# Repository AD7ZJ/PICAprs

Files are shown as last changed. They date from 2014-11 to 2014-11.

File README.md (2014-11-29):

# PIC based APRS Tracking Beacon

I started this project as a fun experiment to see if I could generate an AFSK signal with a small PIC and a resistor ladder network.  It worked out well so I made it into a full tracking beacon.  We fly these on high altitude balloons to track and recover the balloon's payload.  Here's a few of the key features:

- Simple and inexpensive to build.  AFSK is generated using a resistor network so no modem chip is needed
- Adjustable audio output allows interfacing with a variety of radios
- Integrated GPS with helical antenna - no cables to break and works in any orientation
- NMEA data from the GPS is stored on a FAT32 formatted micro SD card
- Software is modular and easy to understand

Well, the last one might be open to debate :-)  It runs on a PIC18F2525 with an SD card hooked up to the SPI port.  I put the GPS and GPS antenna on the same PCB but unfortunately that antenna can no longer be bought from sparkfun - Sarantel seems to be out of business. 

An MPLAB-X project is included and works with the latest version (2.26).  I use the Microchip XC8 compiler.  More details can be seen here: http://wiki.ad7zj.net/wiki/index.php/PIC_APRS_Beacon

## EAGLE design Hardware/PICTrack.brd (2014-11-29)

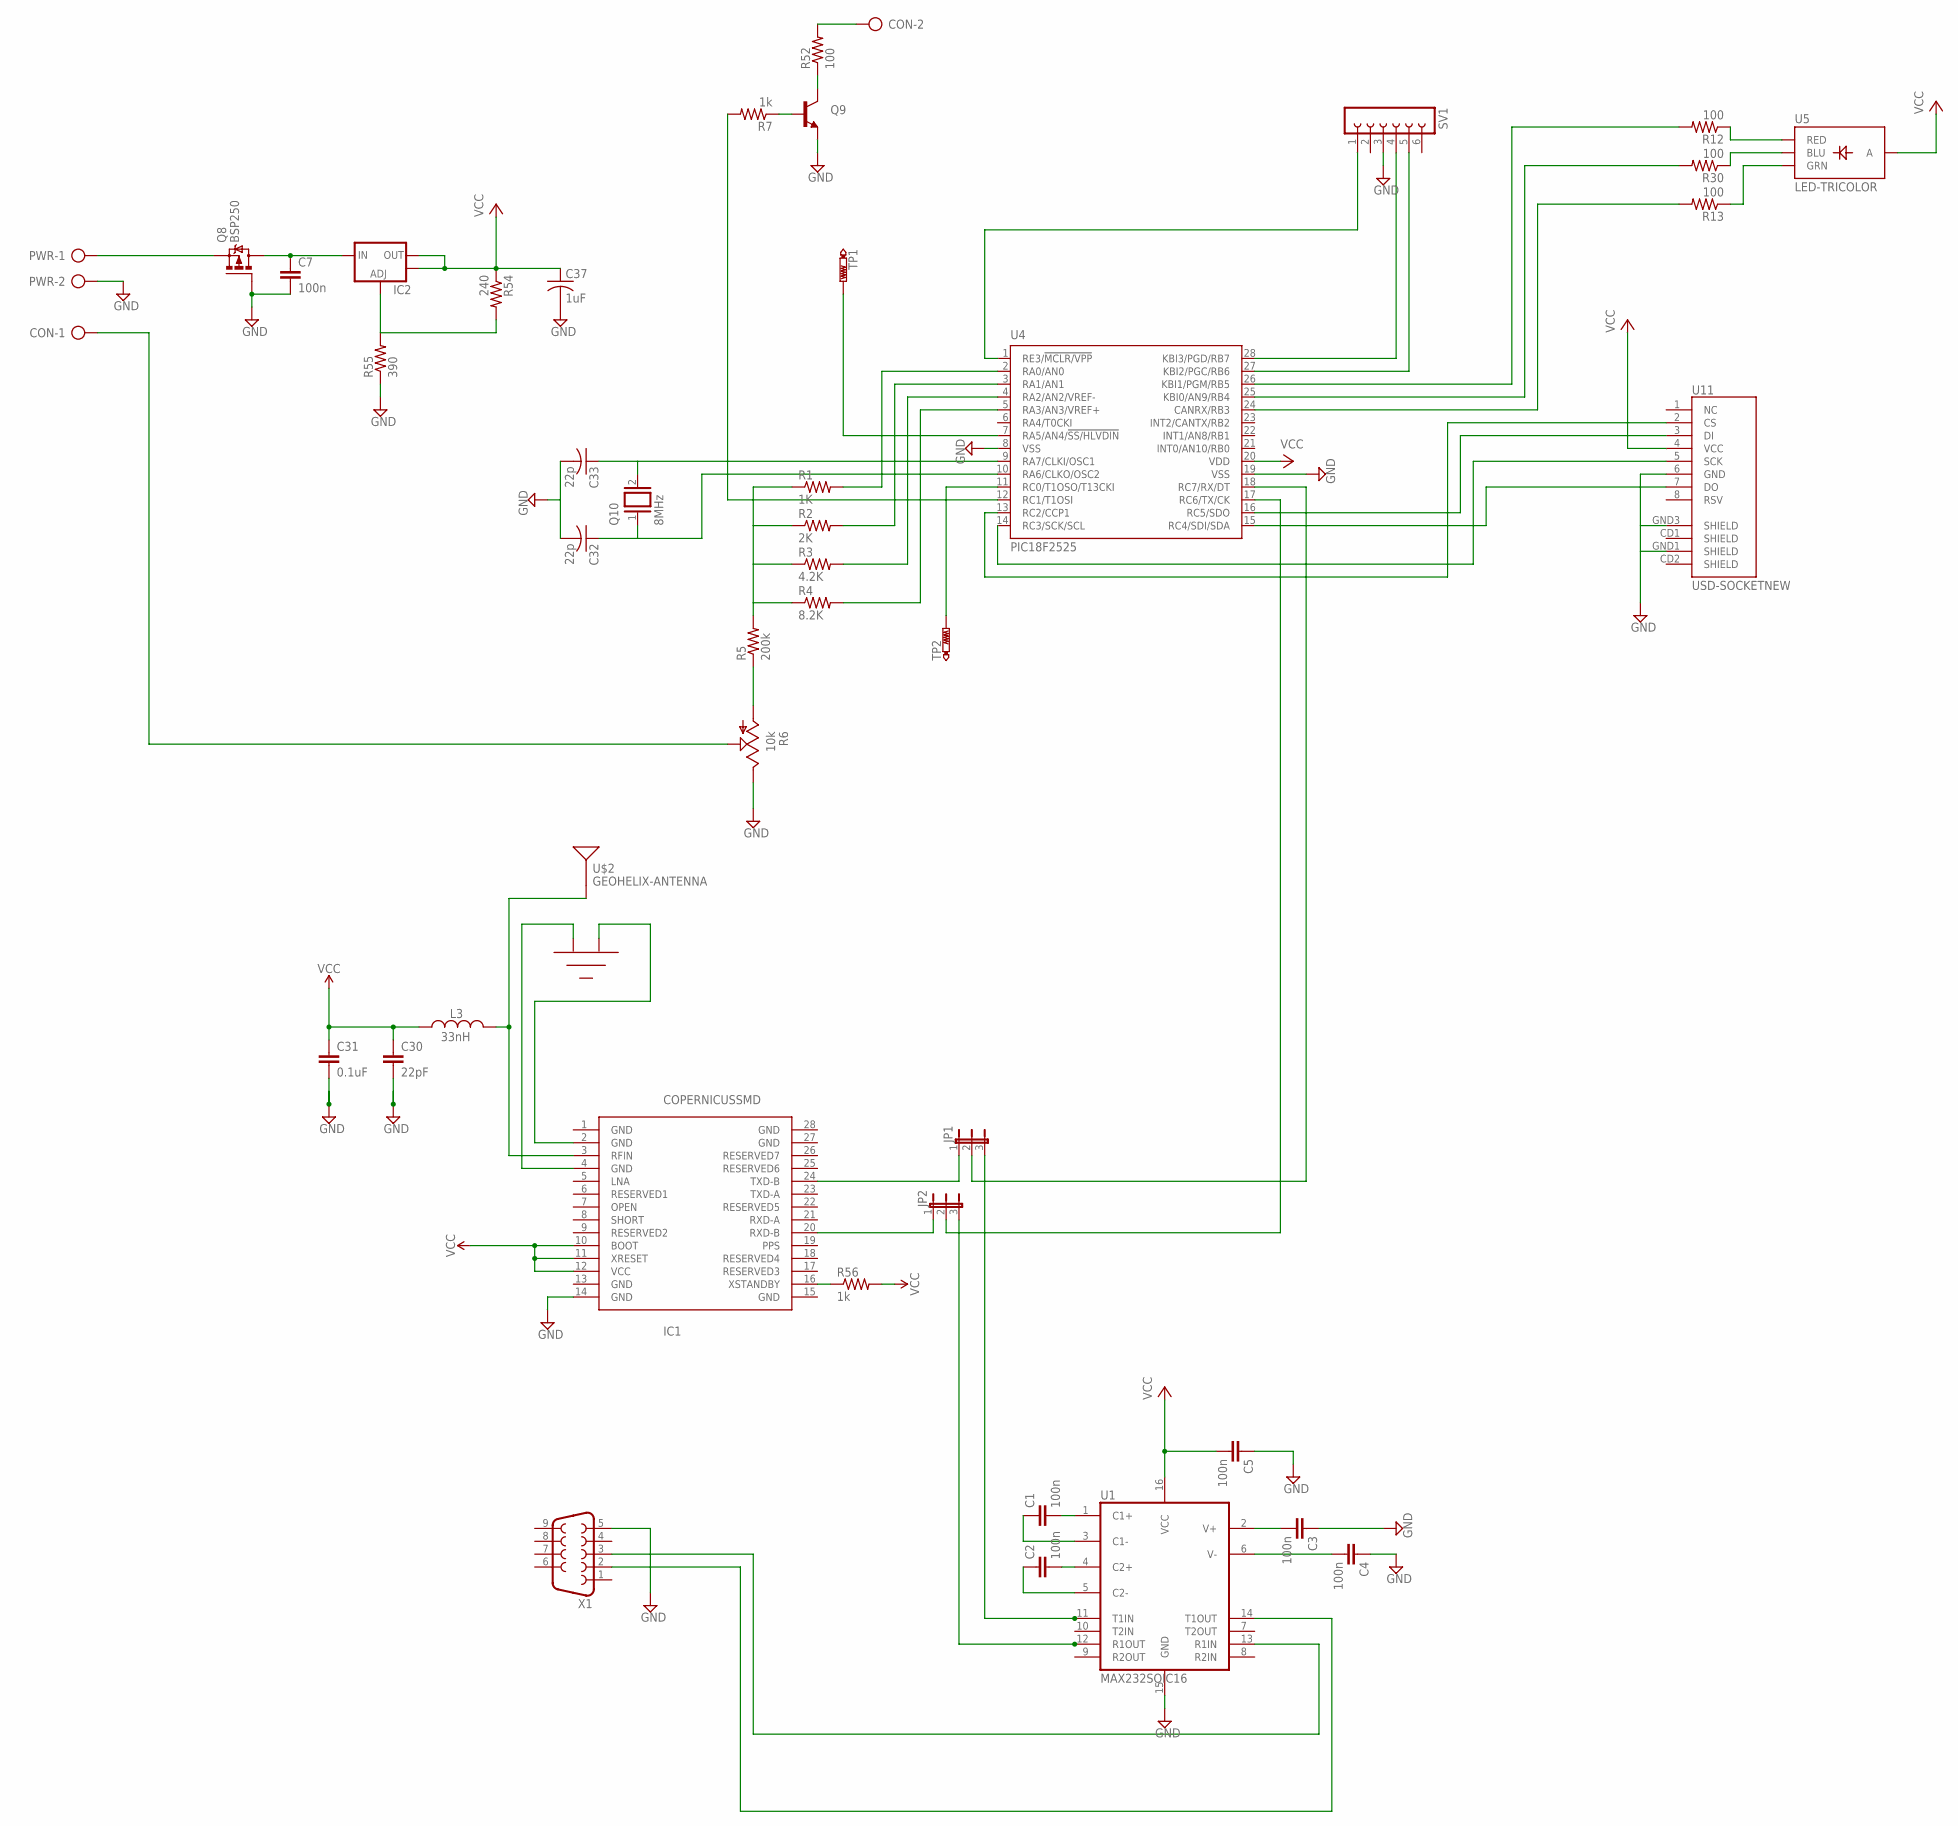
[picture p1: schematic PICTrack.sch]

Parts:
C1, C2, C3, C4, C5, C7: 100n; C0402
C30: 22pF; 0402-CAP
C31: 0.1uF; 0402-CAP
C32, C33: 22p; C0603
C37: 1uF; C025-030X050
CON: AK300/2
IC1: COPERNICUSSMD; COPERNICUS
IC2: V_REG_LM1117SOT223; SOT223
JP1, JP2: JP2E; JP2
L3: 33nH; C0402
PWR: AK300/2
Q8: BSP250; SOT223
Q9: TRANSISTOR_NPNSOT23; SOT23
Q10: 8MHz; QS
R1: 1K; 0411V
R2: 2K; 0411V
R3: 4.2K; 0411V
R4: 8.2K; 0411V
R5: 200k; 0411V
R6: 10k; CA6V
R7, R56: 1k; R0603
R12, R13, R30: 100; R0603
R52: 100; 0411V
R54: 240; R0603
R55: 390; R0603
SV1: FE06-1; FE06
TP1, TP2: PTR1PAD1-13; P1-13
U1: MAX232SOIC16; SO016
U4: PIC18F2525; SO28W
U5: LED-TRICOLOR; LED-TRICOLOR-SMD
U11: USD-SOCKETNEW; MICRO-SD-SOCKET-PP
U$2: GEOHELIX-ANTENNA; HELIXANTENNA
X1: DB9FEMALE; DB9

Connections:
GND: C3.1, C4.1, C5.1, C7.2, C30.2, C31.2, C32.2, C33.2, C37.2, IC1.14 (GND), PWR.2, Q8.1 (G), Q9.2 (E), R6.E, R55.1, SV1.3, U1.15 (GND), U4.8 (VSS), U4.19 (VSS), U11.6 (GND), U11.GND1 (SHIELD), U11.GND3 (SHIELD), X1.5
unnamed: R5.1, R6.A
unnamed: R1.2, U4.2 (RA0/AN0)
unnamed: R2.2, U4.3 (RA1/AN1)
unnamed: R3.2, U4.4 (RA2/AN2/VREF-)
unnamed: R4.2, U4.5 (RA3/AN3/VREF+)
unnamed: R1.1, R2.1, R3.1, R4.1, R5.2
unnamed: PWR.1, Q8.3 (S)
unnamed: C1.2, U1.1 (C1+)
unnamed: CON.1, R6.S
unnamed: C1.1, U1.3 (C1-)
unnamed: C2.2, U1.4 (C2+)
unnamed: C2.1, U1.5 (C2-)
unnamed: C3.2, U1.2 (V+)
unnamed: C4.2, U1.6 (V-)
unnamed: SV1.1, U4.1 (RE3/!MCLR/VPP)
unnamed: SV1.4, U4.28 (KBI3/PGD/RB7)
unnamed: IC1.2 (GND), U$2.P$3 (GND1)
unnamed: TP1.TP, U4.7 (RA5/AN4/!SS/HLVDIN)
unnamed: IC1.16 (XSTANDBY), R56.1
unnamed: R12.1, U5.R (RED)
unnamed: R30.1, U5.B (BLU)
unnamed: TP2.TP, U4.11 (RC0/T1OSO/T13CKI)
unnamed: JP1.3, U1.11 (T1IN)
unnamed: IC2.1 (ADJ), R54.2, R55.2
unnamed: Q9.3 (C), R52.1
unnamed: CON.2, R52.2
unnamed: R7.2, U4.12 (RC1/T1OSI)
unnamed: Q9.1 (B), R7.1
unnamed: IC1.4 (GND), U$2.P$1 (GND)
unnamed: U1.13 (R1IN), X1.3
unnamed: U1.14 (T1OUT), X1.2
unnamed: SV1.5, U4.27 (KBI2/PGC/RB6)
unnamed: U4.15 (RC4/SDI/SDA), U11.7 (DO)
unnamed: U4.14 (RC3/SCK/SCL), U11.5 (SCK)
unnamed: U4.16 (RC5/SDO), U11.3 (DI)
unnamed: U4.13 (RC2/CCP1), U11.2 (CS)
unnamed: IC1.24 (TXD-B), JP1.1
unnamed: C32.1, Q10.1, U4.10 (RA6/CLKO/OSC2)
unnamed: C33.1, Q10.2, U4.9 (RA7/CLKI/OSC1)
unnamed: JP2.3, U1.12 (R1OUT)
unnamed: IC1.20 (RXD-B), JP2.1
unnamed: C7.1, IC2.3 (IN), Q8.2 (D)
unnamed: R13.1, U5.G (GRN)
unnamed: R12.2, U4.26 (KBI1/PGM/RB5)
unnamed: R30.2, U4.25 (KBI0/AN9/RB4)
unnamed: R13.2, U4.24 (CANRX/RB3)
RFIN: IC1.3 (RFIN), L3.2, U$2.P$2 (SIGNAL)
RXD: JP2.2, U4.17 (RC6/TX/CK)
TXD: JP1.2, U4.18 (RC7/RX/DT)
VCC: C5.2, C30.1, C31.1, C37.1, IC1.10 (BOOT), IC1.11 (XRESET), IC1.12 (VCC), IC2.2 (OUT), IC2.4 (OUT), L3.1, R54.1, R56.2, U1.16 (VCC), U4.20 (VDD), U5.A, U11.4 (VCC)

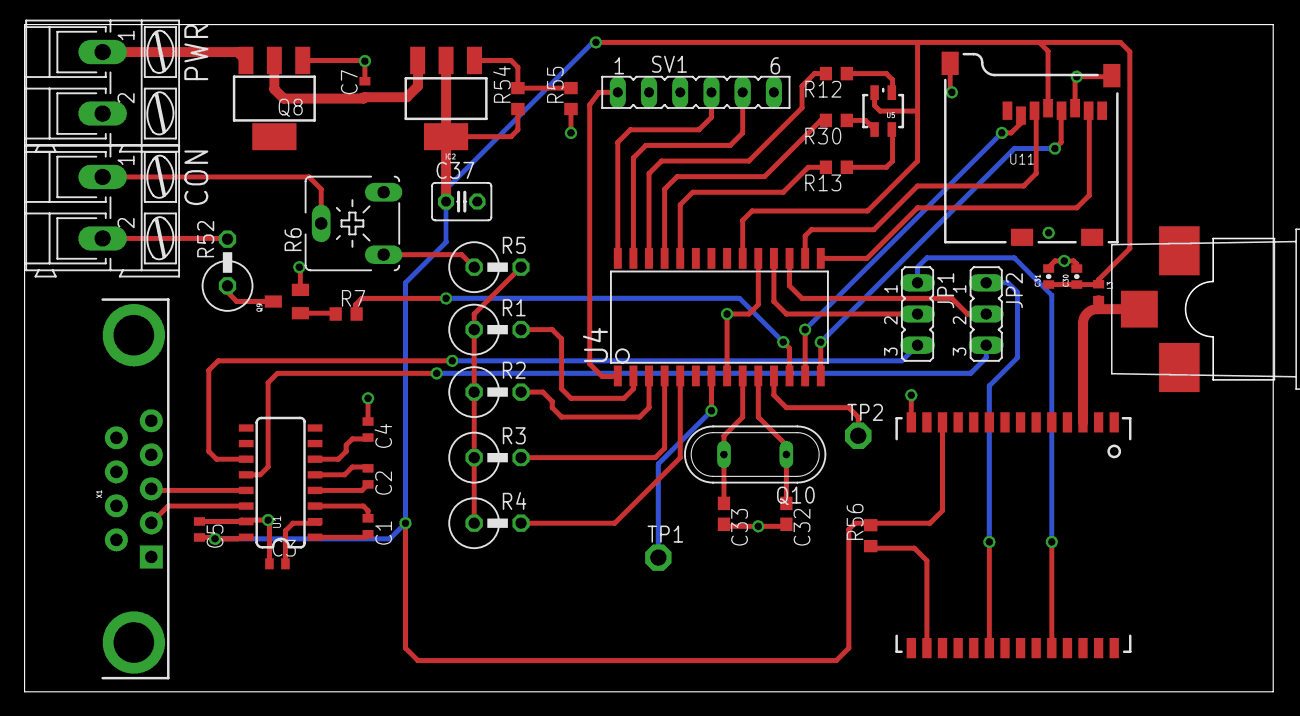
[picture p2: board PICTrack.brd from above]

Board: 2 copper layers, 101.6 x 54.3 mm, 44 parts (0 on the bottom side), 51 nets.

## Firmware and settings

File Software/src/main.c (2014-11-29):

/**
 * @mainpage PICAprs
 *
 * @section overview_sec Overview
 *
 * PICAprs aims to be a self-contained APRS based tracking system that generates
 * modulated audio (AFSK) to interface with an FM transmitter.  It uses an on-board
 * 4 bit resistor DAC followed by an RC LPF to generate the audio.  It expects NMEA
 * (GGA and RMC strings) in from a GPS on the hardware UART ports.  Currently
 * it's designed to run on a Microchip PIC18F2525 clocked at 32 Mhz although porting
 * to another architecture shouldn't be too difficult.  Timing during the packet
 * generation routine is pretty tight and requires interrupts to be disabled until
 * the packet is finished sending.  
 *
 * @section copyright_sec Copyright
 *
 * Copyright (c) 2013 Elijah Brown, AD7ZJ
 *
 *
 * @section gpl_sec GNU General Public License
 *
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
 *
 * @section history_sec Revision History
 *
 *         @subsection v001 V0.01
 *         03 Nov 2013, Initial release.
 *         @subsection v100 V1.00
 *         01 Mar 2014, Release for first flight
 *         @subsection v101 V1.01
 *         25 Jul 2014, Sin lookup table error fixed and experimentally
 *                      tuned the symbol clocks to be closer to nominal values.
 *
 * @defgroup app Main Application
 *
 * @{
 */

#include <htc.h>
#include <stdio.h>
#include <stdlib.h>
#include <string.h>
#include "main.h"
#include "tnc.h"
#include "serial.h"
#include "Engineering.h"
#include "led.h"
#include "fifo.h"
#include "gps.h"
#include "mic-e.h"
#include <math.h>
#include "ff.h"
#include "sd.h"

/// Needed by the compiler for _delay() routines
#define _XTAL_FREQ  32000000

/// Number of system timer ticks in one second
#define ONE_SEC     20
#define FIVE_SEC    100

/*
 * Fuse settings
 */
#pragma config OSC      = INTIO67
#pragma config WDT      = OFF
#pragma config BOREN    = OFF
#pragma config DEBUG    = ON
#pragma config MCLRE    = OFF
#pragma config LVP      = OFF

/*
 * Forward definitions
 */
void sysInit(void);
void LedBootBlink(void);

/// Enumeration of serial port modes
typedef enum {
    STARTUP,
    GPS_MODE,
    CONSOLE_MODE
} SER_PORT_MODE;

/// Holds the last received byte from the serial port
volatile char serbuff = 0;

/// system 50ms timer tick
volatile static uint32_t sysTick;

/// keeps track of the one second tick
static uint32_t oneSecTick;

/// keeps track of the GPS status LED's tick
static uint32_t statusLedOffTick;

/// Keeps track of whether the serial port is in console mode or GPS mode
SER_PORT_MODE serMode;

/**
 * Sends a MIC-E position packet
 *
 * @param gps GPSData structure containing location to send
 */
void SendPosition(GPSData * gps) {
    MicEEncode(gps);
    TncPreparePacket(MicEGetInfoField(), MicEGetDestAddress());
    printf("Lat: %ld Long: %ld\r\n", gps->latitude, gps->longitude);

    // transmit the Mic-E compressed packet
    RadioTX();
    TncSendPacket();
    RadioRX();
}

/**
 * Sends an AX.25 status packet
 *
 * @param gps GPSData structure from which to get altitude, dop, and number of tracked satelites
 */
void SendStatus(GPSData * gps) {
    char buffer[50];
    sprintf(buffer, ">ANSR %ld' %d.%01ddop %dtrk www.ansr.org\015", (int32_t)(gps->altitude / 30.48), (uint16_t)(gps->dop / 10), (uint16_t)(gps->dop % 10), (uint16_t)gps->trackedSats);
    TncPreparePacket(buffer, "APRS  ");
    printf("%s\n", buffer);

    // transmit the packet
    RadioTX();
    TncSendPacket();
    RadioRX();
}

FATFS fileSystem;   /* Work area (file system object) for logical drive */
FIL logFile;

/**
 * Main application loop
 */
void main(void) {
    FRESULT res;
    WORD bw, btw;
    char buffer[80];

    sysInit();
    SerialInit();
    GPSData * gps;

    // get the pointer to the GPS data structure
    gps = GpsGetData();

    // configure the TNC
    TncConfigDefault();

    // indicate the system is up and running
    LedBootBlink();

    SetLED(3, 1);
    // wait for someone to press '`' a few times to enter console mode
    SerialPutst("Press '`' to enter console mode\r\n");
    while (sysTick < FIVE_SEC) {
        if (serbuff == '`') {
            serMode = CONSOLE_MODE;
            break;
        }
    }
    SetLED(3, 0);


    /* Register work area to the default drive */
    res = f_mount(&fileSystem, "", 0);
    if (res)
        printf("Failed to mount filesystem!\r\n");

    /* Open a text file */
    res = f_open(&logFile, "test.txt", FA_OPEN_ALWAYS | FA_WRITE);
    if (res)
        printf("Failed to open file: %d\r\n", res);

    /* seek to end of the file */
    f_lseek(&logFile, f_size(&logFile));

    // if console mode was not selected, default to using the GPS
    if (serMode != CONSOLE_MODE) {
        serMode = GPS_MODE;
        
        TncPreparePacket(">Successful boot!\015", "APRS  ");
        // transmit the packet
        RadioTX();
        TncSendPacket();
        RadioRX();
    }

    while (1) {
        if (serMode == CONSOLE_MODE)
            EngineeringConsole();
        else {
            // Read data from the GPS
            GpsUpdate();

            if (GpsIsDataReady()) {
                if (gps->fixType != NoFix) {
                    switch (gps->seconds) {
                        case 15:
                        case 45:
                            SendPosition(gps);
                            break;

                        case 23:
                            // send a status packet
                            SendStatus(gps);
                            break;
                    }
                }
                SetLED(1, 1);
                if (gps->fixType == NoFix)
                    statusLedOffTick = sysTick + 10;
                else
                    statusLedOffTick = sysTick + 2;
            }

            // 5s tasks
            if (sysTick > oneSecTick) {
                //printf("Uptime: %ul\r\n", uptime);
                oneSecTick = sysTick + FIVE_SEC;

                SetLED(3, 1);

                f_sync(&logFile);

                SetLED(3, 0);
            }

            // update the GPS status LED
            if (sysTick > statusLedOffTick)
                SetLED(1, 0);
        }
    }
}

/**
 * Blink the LEDs in a pattern to signal a successful boot
 */
void LedBootBlink(void) {
    uint8_t i;
    for (i = 0; i < 3; i++) {
        SetLED(1, 1);
        __delay_ms(10);
        SetLED(1, 0);
        SetLED(2, 1);
        __delay_ms(10);
        SetLED(2, 0);
        SetLED(3, 1);
        __delay_ms(10);
        SetLED(3, 0);
        __delay_ms(10);
        __delay_ms(10);
        __delay_ms(10);
    }
}

/**
 * Initialize hardware
 */
void sysInit(void) {
    // port directions: 1=input, 0=output
    LATA = 0x00;
    TRISA = 0b00000000;
    LATB = 0x00;
    TRISB = 0b00000000;
    LATC = 0x00;
    TRISC = 0b11010000;

    // multiply internal 8 MHz clock x4
    OSCCON = 0b01110000;
    PLLEN = 0x01;
    // All digital inputs
    ADCON1 = 0x0F;

    // Clear the timers
    TMR1H = 0x00;
    TMR1L = 0x00;

    // Enable timer 1
    T1CONbits.TMR1ON = 0x1;
    // System clock is not derived from Timer1 Osc
    T1CONbits.T1RUN = 0x0;
    // Timer1 Osc is disabled
    T1CONbits.T1OSCEN = 0x0;
    // Use Fosc/4 for the clock source
    T1CONbits.TMR1CS = 0x0;
    // prescaler of 1:8
    T1CONbits.T1CKPS = 0x3;
    // enable its interrupt
    TMR1IE = 0x01;

    // enable Timer2
    T2CONbits.TMR2ON = 0x1;
    // Prescale of 1:2
    T2CONbits.T2OUTPS0 = 0x1;

    // GIE, PEIE Interrupts
    GIE = 0x1;
    PEIE = 0x1;
    INTCON = 0b11000000;
    RCIE = 0x01;

    // Put the serial port in startup mode
    serMode = STARTUP;

    // zero the uptime
    sysTick = 0;

    sysTick = 0;
    oneSecTick = 0;
    statusLedOffTick = 0;
}

/**
 * System interrupt handler
 */
interrupt isr(void) {
    // Serial receive interrupt
    if (RCIF) {
        serbuff = RCREG;
        if (serMode != STARTUP) {
            FifoWrite(serbuff);
        }

        // clear any overrun errors
        if (OERR)
        {
            CREN=0;
            CREN=1;
        }
    }

    // Timer 1 interrupt every 50ms
    if (TMR1IF) {
        // Clear interrupt flag & reload timer
        TMR1IF = 0x00;
        TMR1H = 0x3C;
        TMR1L = 0xAF;
        sysTick++;

        // update the filesystem timers
        disk_timerproc();
    }
}

/** @} */

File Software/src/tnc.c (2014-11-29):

#include <htc.h>
#include <string.h>
#include "main.h"
#include "tnc.h"
#include "fifo.h"
#include "serial.h"

/**
 * @defgroup ax25packet AX.25 Packet Creation
 *
 * Contains functions to control the 4-bit resistor DAC, create packets, 
 * and setup the software TNC
 * @{
 */

/**
 * Table of values to generate a sin wave.  Each value represents the value
 * to jump to after an equal increment in time.  Note this is highly dependant
 * on the particular HW configuration :-)
 */
static unsigned char sinDAC[] = {
    0b0001, 0b0101, 0b1011, 0b0111, 0b1111, 0b0111,
    0b1011, 0b0101, 0b0001, 0b1010, 0b0100,
    0b1000, 0b0000, 0b1000, 0b0100, 0b1010
};

static uint16_t tncIndex, tncLength;
static uint8_t tncBitCount, tncShift, tncLastBit, tncMode;
static uint8_t tncBitStuff, tncBuffer[TNC_MAX_TX], sinIndex;
static uint16_t timeElapsed = 0;

/// Structure containing the TNC configuration (callsign, digi path, etc)
CONFIG_STRUCT config;

#define _XTAL_FREQ 32000000

/**
 * Configure the TNC's callsign, SSID, and digipeat path.
 */
void TncConfigDefault() {
    // Station ID, relay path, and destination call sign and SSID.
    strcpy(config.callSign, "AD7ZJ ");
    config.callSignSSID = 11;
    strcpy(config.destCallSign, "APRS  ");
    strcpy(config.relayCallSign1, "GATE  ");
    strcpy(config.relayCallSign2, "WIDE2 ");
    config.relayCallSignSSID1 = 0;
    config.relayCallSignSSID2 = 1;

    // Number of TNC flag bytes sent before data stream starts.  (350mS) 1 byte = 6.6mS
    config.txDelay = 53;

    // Flight operation time.
    config.flightTime = 0;
}

/**
 * Calculate the CRC-16 CCITT of <b>buffer</b> that is <b>length</b> bytes long.
 *
 * @param buffer Pointer to data buffer.
 * @param length number of bytes in data buffer
 *
 * @return CRC-16 of buffer[0 .. length]
 */
uint16_t CRC16(uint8_t *buffer, uint16_t length) {
    uint16_t i, dbit, crc, value;

    crc = 0xffff;

    for (i = 0; i < length; ++i) {
        value = buffer[i];

        for (dbit = 0; dbit < 8; ++dbit) {
            crc ^= (value & 0x01);
            crc = (crc & 0x01) ? (crc >> 1) ^ 0x8408 : (crc >> 1);
            value = value >> 1;
        }
    }

    return crc ^ 0xffff;
}

/**
 * Prepare an AX.25 packet for transmission.  This function takes a char buffer as
 * input and operates on tncBuffer.
 *
 * @param message pointer to NULL terminate message string
 * @param destaddr pointer to the destination address
 */
void TncPreparePacket(uint8_t * message, uint8_t * destaddr) {
    uint16_t i, crc;
    uint8_t *outBuffer;

    // If we are currently sending, then ignore this packet.
    if (tncMode == TNC_TX_PREPARE || tncMode == TNC_TX_SYNC || tncMode == TNC_TX_DATA || tncMode == TNC_TX_END)
        return;

    tncMode = TNC_TX_PREPARE;

    // Set a pointer to our output buffer.
    outBuffer = tncBuffer;

    // Includes source (7), dest (7), control field (1), protocol ID (1), and end of message (1).
    tncLength = 17;

    // Set the destination address.  AX.25 requires all callsigns to be ASCI shifted one left.  This
    // essentially just drops the parity bit
    for (i = 0; i < 6; ++i)
        *outBuffer++ = destaddr[i] << 1;

    // Set destination to SSID-0
    *outBuffer++ = 0x60;

    // Set the source address, again shifted one left
    for (i = 0; i < 6; ++i)
        *outBuffer++ = config.callSign[i] << 1;

    // Set the SSID.
    *outBuffer++ = 0x60 | (config.callSignSSID << 1);

    // Add relay path 1.
    if (*config.relayCallSign1 != 0) {
        for (i = 0; i < 6; ++i)
            *outBuffer++ = config.relayCallSign1[i] << 1;
        *outBuffer++ = 0x60 | (config.relayCallSignSSID1 << 1);
        tncLength += 7;
    }

    // Add relay path 2.
    if (*config.relayCallSign2 != 0) {
        for (i = 0; i < 6; ++i)
            *outBuffer++ = config.relayCallSign2[i] << 1;
        *outBuffer++ = 0x60 | (config.relayCallSignSSID2 << 1);
        tncLength += 7;
    }

    // Set bit-0 of the last SSID.
    *(outBuffer - 1) |= 0x01;

    // Set the control field (UI) and protocol ID.
    *outBuffer++ = 0x03;
    *outBuffer++ = 0xf0;

    // Add the message to the buffer
    while (*message != 0) {
        *outBuffer++ = *message++;
        ++tncLength;
    }

    // Add the end of message character.
    *outBuffer++ = 0x0d;

    // Calculate and append the CRC.
    crc = CRC16(tncBuffer, tncLength);
    *outBuffer++ = crc & 0xff;
    *outBuffer = (crc >> 8) & 0xff;

    // Update the length to include the 2 CRC bytes.
    tncLength += 2;

    // Prepare to send the packet
    tncBitCount = 0;
    tncShift = 0x7e;
    tncLastBit = 0;
    tncIndex = 0;
    tncMode = TNC_TX_SYNC;
}

/**
 * Generate a continuous mark or space tone to allow for frequency calibration
 *
 * @param bitValue zero for a 1200hz tone, non-zero for a 2200hz tone
 */
void TncCalTones(unsigned bitValue) {
    while (FifoRead() != 'q') {
        // Output the next step of the sin wave.  The rest of the code in this function determines the
        // frequency of this wave.
        PORTC = sinDAC[sinIndex];
        sinIndex++;
        sinIndex &= 0x0F;

        if (bitValue)
            PR2 = MARK;
        else
            PR2 = SPACE;

        while (!TMR2IF) {
            // wait for the timer to overflow.  This wait time determines the frequency of the sin
        }
        TMR2IF = 0;
    } // end while loop
}
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

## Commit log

2013-02-09 Fixed build process to compile c files individually
    [main.c]
2013-03-10 Added engineering module and refactored some of the other modules. Switched to X IDE
2013-03-27 Fixed the formatting in ax25.c and fixed the issue with the baud rate 'slipping'. This was keeping AGWPE and others from being able to decode the packets.
    [main.c]
2013-11-01 Added schematic and board layout to the project
    [PICTrack.brd, PICTrack.sch]
2013-11-24 Added the LED module. Added logic in the main routine to flash the LED when GPS packets are received.
2013-12-22 Restructured project directories and switched to XC8 compiler
2013-12-25 Disabled interrupts during packet transmit to avoid corrupting packets if a character is received from the GPS, causing an interrupt. Added logic to the UART RX interrupt handler to clear any overrun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
    [main.c, tnc.c]
2014-01-04 Fixed timer 1 configuration so it fires an interrupt every 50ms
    [main.c]
2014-03-01 Minimized rounding errors and added a boot message.
    [main.c, tnc.c]
2014-07-26 Fixed sin lookup table, tweaked baud rate clock experimentally to be closer to 1200 baud
    [tnc.c]
2014-11-29 Cleaned up unused files and fixed a few comments, updated major revisions in main doxy header
    [PICTrack.brd, PICTrack.sch]

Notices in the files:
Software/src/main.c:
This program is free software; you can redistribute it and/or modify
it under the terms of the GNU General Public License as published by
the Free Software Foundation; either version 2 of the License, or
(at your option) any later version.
